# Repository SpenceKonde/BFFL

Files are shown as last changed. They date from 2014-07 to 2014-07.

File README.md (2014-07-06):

BFFL
====

Code and hardware specs for Big F'n FlashLight (BFFL)

Concept
====

The BFFL represents the extension of commercially available high power LED flashlights to their illogical conclusion. The BFFL uses a 150W LED emitter, and is powered by 24 18650 lithium ion batteries. The BFFL easily outshines typical home outdoor spotlights. 

Control
====
Control is provided by an ATtiny84 microcontroller. Control inputs consist of a trigger, brightness control, and standby light.  Brightness is adjustable down to 1/32 power via PWM, and it can set to run at 1/32 to 1/8 power when the trigger is not depressed (so you can find your way with it pointed down, and then press the trigger to get a much brighter search light) Battery status is displayed via an RGB led, and the temperature of the emitter is monitored to prevent overheating in the event of a cooling failure. The fan used has PWM control, and the speed of the fan is controlled by the measured temperature.

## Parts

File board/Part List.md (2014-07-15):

| ID | Part  | Notes |
| --- |---| -----|
| C1,C3,C4 | 0.1uf ceramic 1206 ||
| C2 | 22uf tantalum
| LED1 | DC-LED11119 5050 RGB LED | Battery status light |
| LED2 | Red 1206 LED | Temp. warning light|
| LED3 | Green 1206 LED |Power light|
| R1 | 1.2k Ohm 1206 | Ballast for LED2 |
| R2 | 470 Ohm 1206 | Ballast for LED3 |
| R3+ | 1.2k Ohm 1206 | Ballast for LED1, Green |
| R4+ | 470 Ohm 1206 | Ballast for LED1, Red |
| R5+ | 1.2k Ohm 1206 | Ballast for LED1, Blue |
| R6 | 10K Ohm | Vbat divider |
| R7 | 1k Ohm | Vbat divider |
| R8* | 1K Ohm | Pulldown for temp sensor |
| R9 | 10k Ohm | Pulldown for MOSFET |
|JP1| 2 pin KK-100 header | 12v in |
|JP2| 7 pin KK-100 header | controls |
|JP3| JP4: Screw terminals | LED |
|JP4| 3 pin KK-100 header | Temp |
|JP5| 4 pin KK-100 header** | Fan |
|JP6| 2x3 pin 0.1" header | AVR ISP |
| Q1 | AO4438 ||
| U1  | ATINY84A-SU-ND ||
| U2  | TLV1117-50CDCYR | 5v LDO regulator

** Tab on header must be shaved down in order to fit the PWM fan connector, which expects the keying tab to be the size that it is on a standard 3 pin KK-100 connector.

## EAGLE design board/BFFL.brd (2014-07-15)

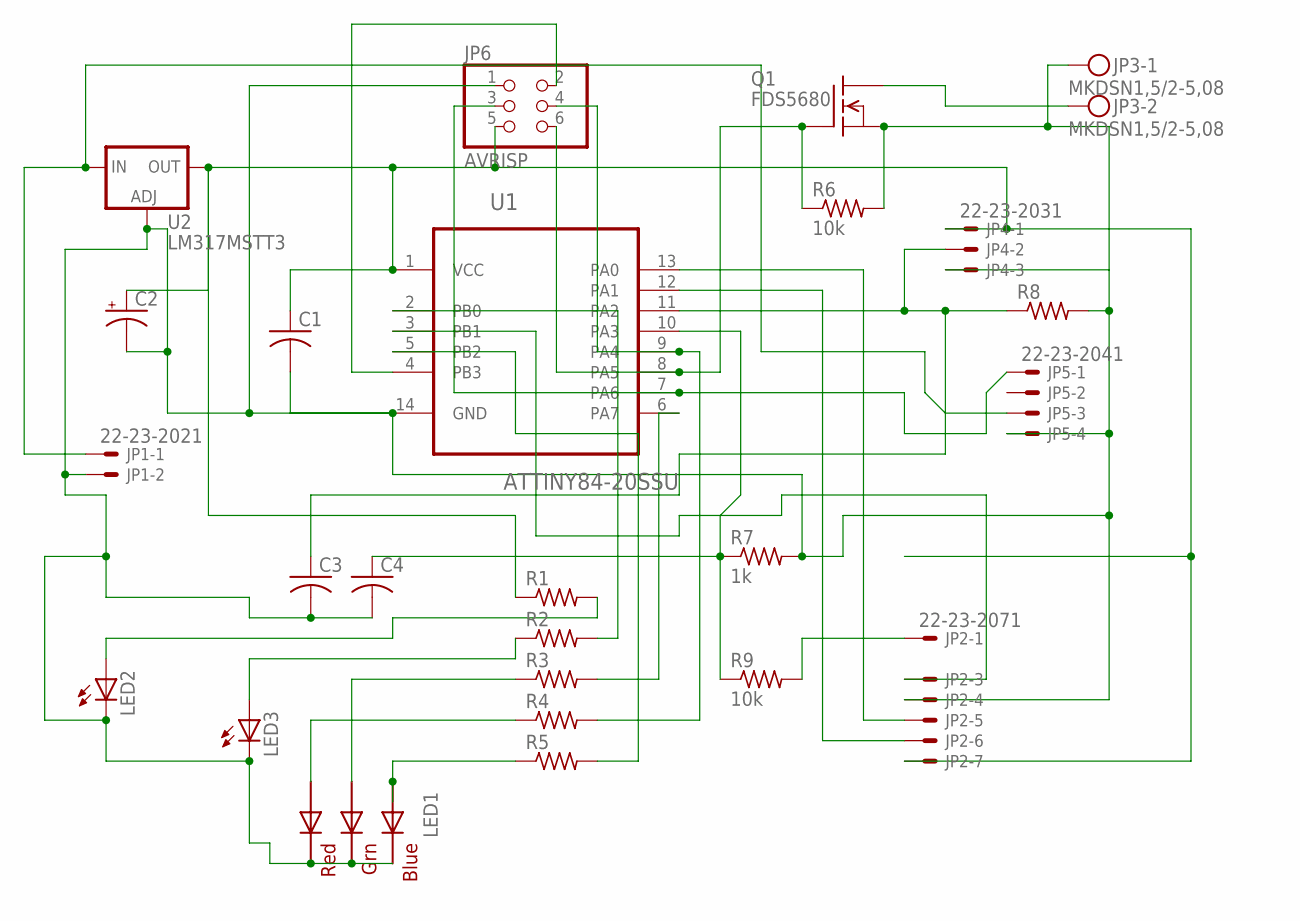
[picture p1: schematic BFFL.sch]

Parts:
C1, C3, C4: C-USC1206K; C1206K
C2: CPOL-USC/6032-28W; C/6032-28W
JP1: 22-23-2021
JP2: 22-23-2071
JP3: MKDSN1,5/2-5,08
JP4: 22-23-2031
JP5: 22-23-2041
JP6: AVRISP; 2X03
LED1: RGBLED5050
LED2, LED3: LEDCHIPLED_1206; CHIPLED_1206
Q1: FDS5680; SO-8
R1, R2, R3, R4, R5, R8: R-US_R1206; R1206
R6, R9: 10k; R1206
R7: 1k; R1206
U1: ATTINY84-20SSU; SOIC127P600X175-14N
U2: LM317MSTT3; SOT223

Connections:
unnamed: JP2.1, R9.2
unnamed: C4.1, R7.1, R9.1, U1.10 (PA3)
unnamed: JP1.1, JP5.3, U2.3 (IN)
unnamed: JP6.6, Q1.4 (G), R6.1, U1.8 (PA5)
unnamed: R2.2, U1.2 (PB0)
unnamed: C1.1, C2.+, JP2.7, JP4.1, JP6.5, R1.1, U1.1 (VCC), U2.4 (OUT)
unnamed: LED2.A, R1.2
unnamed: LED3.A, R2.1
unnamed: LED1.2 (RED_A), R4.1
unnamed: LED1.1 (GREEN_A), R3.1
unnamed: LED1.3 (BLUE_A), R5.1
unnamed: JP3.2, Q1.5 (D), Q1.6 (D), Q1.7 (D), Q1.8 (D)
unnamed: C1.2, C2.-, C3.2, C4.2, JP1.2, JP2.4, JP3.1, JP4.3, JP5.4, JP6.1, LED1.4 (BLUE_C), LED1.5 (RED_C), LED1.6 (GREEN_C), LED2.C, LED3.C, Q1.1 (S), Q1.2 (S), Q1.3 (S), R6.2, R7.2, R8.2, U1.14 (GND), U2.1 (ADJ)
unnamed: R5.2, U1.5 (PB2)
unnamed: R3.2, U1.6 (PA7)
unnamed: JP5.1, JP6.3, U1.7 (PA6)
unnamed: JP2.3, U1.3 (PB1)
unnamed: JP6.4, R4.2, U1.9 (PA4)
unnamed: C3.1, JP4.2, R8.1, U1.11 (PA2)
unnamed: JP2.5, U1.13 (PA0)
unnamed: JP2.6, U1.12 (PA1)
unnamed: JP6.2, U1.4 (PB3)

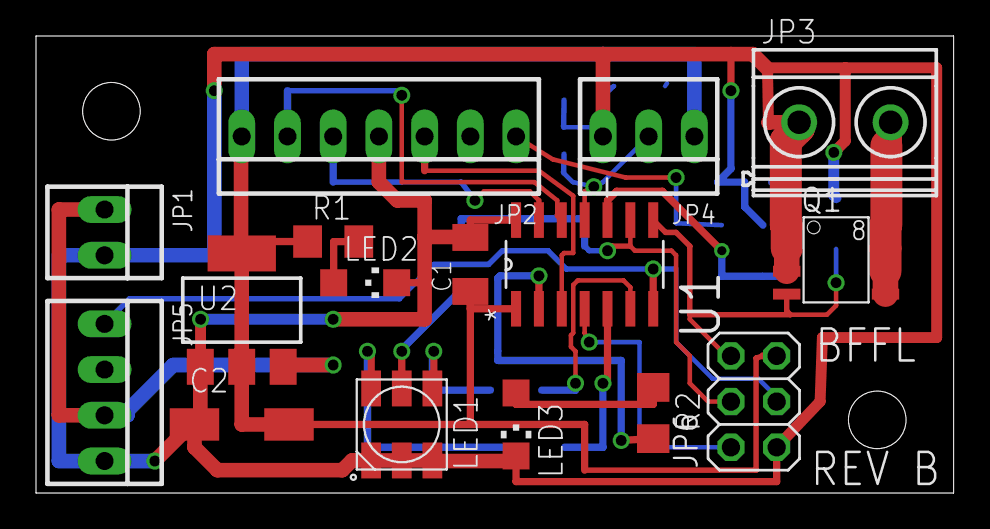
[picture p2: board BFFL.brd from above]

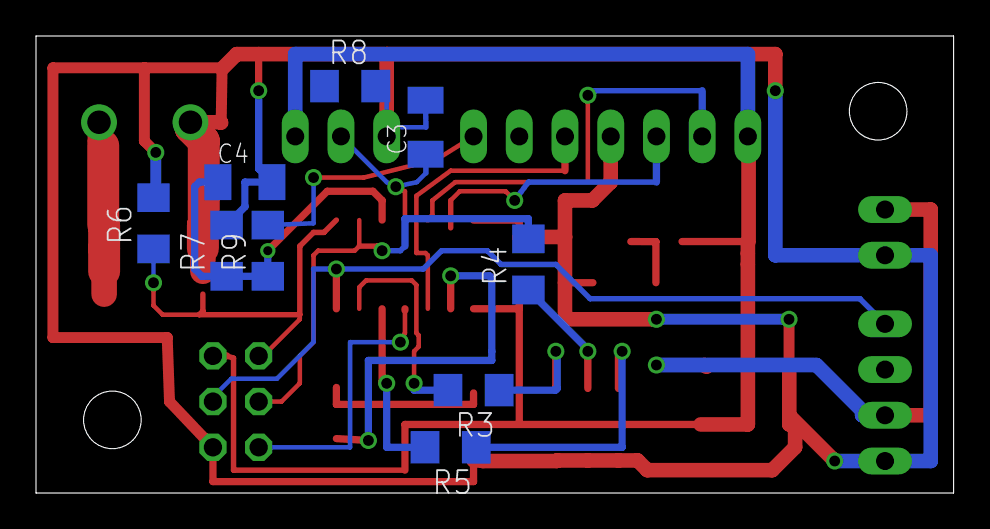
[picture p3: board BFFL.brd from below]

Board: 2 copper layers, 51.0 x 25.4 mm, 25 parts (9 on the bottom side), 22 nets.

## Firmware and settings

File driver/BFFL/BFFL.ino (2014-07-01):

#include <EEPROM.h>
int led_out=5;
int bat_lvl_low=4;
int bat_lvl_mid=7;
int bat_lvl_high=8;
int temp_led=10;
int idle_in=0;
int temp_in=2;
int v_in=3;
int fan_out=6;
int pwm_in=1;
int trig_in=9;
//int trig_in=0;
int cellcount=6;
//5v = 1024;
//3v minimum
//10:1 voltage division
int vlow=55*cellcount;
int vwarn=62*cellcount;
int vmid=68*cellcount;
int vhigh=76*cellcount;
// MCP9701A
// Vzero=400mv=82 from AnalogrRead()
// 19.7 (4 1024th's of 5v) per degree C
// Max temp 50C = 282
// warning temp = 45C 262
int twarn=262;
int tmax=282;
int tfan=202;
int idle_thresh=512;
int idle_min=8;
int idle_max=32;
int idle_div=400;
int min_bright=8;
int throttle_bright=160;
int tempblink=0;
int batblink=0;
int voltage_avg=0;
int lasttrig=1;
int temp_avg=0;
int batthrottle=0;
int batthrottlemargin=4;


void setup() {
  cellcount=EEPROM.read(0);
  vlow=EEPROM.read(4)*cellcount;
  vwarn=EEPROM.read(3)*cellcount;
  vhigh=EEPROM.read(1)*cellcount;
  vmid=EEPROM.read(2)*cellcount;
  batthrottlemargin=EEPROM.read(5);
  idle_thresh=EEPROM.read(0x0A)*4;
  idle_min=EEPROM.read(0x0B);
  idle_max=EEPROM.read(0x0C);
  idle_div=EEPROM.read(0x0D)*4;
  min_bright=EEPROM.read(0x0E);
  throttle_bright=EEPROM.read(0x0F);
  int tbase=EEPROM.read(0x10);
  twarn=tbase+EEPROM.read(0x12);
  tmax=tbase+EEPROM.read(0x11);
  tfan=tbase+EEPROM.read(0x13);
  pinMode(temp_in,INPUT);
  pinMode(pwm_in,INPUT);
  pinMode(trig_in,INPUT_PULLUP);
  pinMode(v_in,INPUT);
  pinMode(temp_led,OUTPUT);
  pinMode(led_out,OUTPUT);
  digitalWrite(led_out,0);
  pinMode(bat_lvl_low,OUTPUT);
  pinMode(bat_lvl_high,OUTPUT);
  pinMode(bat_lvl_mid,OUTPUT);
  pinMode(fan_out,OUTPUT);
  pinMode(idle_in,INPUT);
  voltage_avg=analogRead(v_in);
  temp_avg=analogRead(temp_in);
}


void loop() {
  int trig=digitalRead(trig_in);
  int voltage=analogRead(v_in);
  int temp=analogRead(temp_in);
  temp_avg=(temp_avg*9+temp)/10;
  voltage_avg=(voltage_avg*9+voltage)/10;
  int idle=analogRead(idle_in);
  //temp_avg=temp;
  //voltage_avg=voltage;
  if ((trig==1 && idle < idle_thresh) || temp_avg >= tmax || voltage_avg <= vlow) {
    digitalWrite(led_out,0);
  } else {
    if (temp_avg < tmax && ((voltage_avg > vlow) && ( lasttrig==0 || trig==1)) || (voltage_avg > vwarn)) { //don't let them turn it on if it's below vwarn but above vlow, but let them keep it on until it reaches vlow.
      int pwm_adjust=analogRead(pwm_in);
      pwm_adjust=max(min(pwm_adjust/3,255),min_bright);
      if (trig==1) { //idle mode 
        int tidle=idle-idle_thresh;
        tidle=(tidle*(idle_max-idle_min))/idle_div;
        tidle+=idle_min;
        tidle=min(tidle,idle_max);
        pwm_adjust=tidle;
      }
      if (temp_avg > twarn ||  voltage_avg < vwarn || (voltage_avg < (vwarn+batthrottlemargin*cellcount) && batthrottle==1)) {
        pwm_adjust=min(pwm_adjust,throttle_bright);
        
         if (voltage_avg < vwarn) {
           batthrottle=1;
         }
      } else   if (voltage_avg > (vwarn+batthrottlemargin*cellcount)) {
         batthrottle=0;
      }
      if (pwm_adjust==255) {
        digitalWrite(led_out,1);
      } else {
        analogWrite(led_out,pwm_adjust);
      }
    }
  }
  if (temp_avg > twarn) {
    digitalWrite(temp_led,1);
  } else {
    digitalWrite(temp_led,0);
  }
  if (voltage_avg > vhigh) {
    digitalWrite(bat_lvl_high,1);
    digitalWrite(bat_lvl_mid,0);
    digitalWrite(bat_lvl_low,0);
  }else if (voltage_avg > vmid) {
    int brt=(255*(voltage_avg-vmid))/(vhigh-vmid);
    analogWrite(bat_lvl_high,brt);
    analogWrite(bat_lvl_mid,255-brt);
    digitalWrite(bat_lvl_low,0);
  } else if (voltage_avg > vwarn) {
    digitalWrite(bat_lvl_mid,1);
    digitalWrite(bat_lvl_low,0);
    digitalWrite(bat_lvl_high,0);
  } else if (voltage_avg > vlow) {
    int brt=(255*(voltage_avg-vlow))/(vwarn-vlow);
    digitalWrite(bat_lvl_low,1);
    analogWrite(bat_lvl_mid,brt);
    digitalWrite(bat_lvl_high,0);
  } else {
    digitalWrite(bat_lvl_low,1);
    digitalWrite(bat_lvl_mid,0);
    digitalWrite(bat_lvl_high,0);
  }
  if (temp_avg > twarn) {
    digitalWrite(fan_out,1); //turn fan on full blast!
  } else if (temp_avg > tfan) {
    analogWrite(fan_out,134+(temp_avg-tfan)*2);
  } else {
    digitalWrite(fan_out,0);
  }
}





/*
void loop() {
  int trig=digitalRead(trig_in);
  int voltage=analogRead(v_in);
  int temp=analogRead(temp_in);
  temp_avg=(temp_avg*9+temp)/10;
  voltage_avg=(voltage_avg*9+voltage)/10;
  int idle=analogRead(idle_in);
  //int idle=0;
  //temp_avg=temp;
  //voltage_avg=voltage;
  if ( (trig==1 || idle > idle_thresh) || temp_avg >= tmax || voltage_avg <= vlow) {
    digitalWrite(led_out,0);
  } else {
    if (temp_avg < tmax && ((voltage_avg > vlow) && lasttrig==0) || (voltage_avg > vwarn)) { //don't let them turn it on if it's below vwarn but above vlow, but let them keep it on until it reaches vlow.
      int pwm_adjust=analogRead(pwm_in);
      if (trig==1) { //idle mode 
        int tidle=idle-idle_thresh;
        tidle=(tidle*(idle_max-idle_min))/idle_div;
        tidle+=idle_min;
        tidle=min(tidle,idle_max);
        pwm_adjust=tidle;
      }
      pwm_adjust=max(min(pwm_adjust/3,255),min_bright);
      if (temp_avg > twarn ||  voltage_avg < vwarn || (voltage_avg < (vwarn+batthrottlemargin*cellcount) && batthrottle==1)) {
        pwm_adjust=min(pwm_adjust,throttle_bright);
         if (voltage_avg < vwarn) {
           batthrottle=1;
         }
      } else   if (voltage_avg > (vwarn+batthrottlemargin*cellcount)) {
         batthrottle=0;
      }
      if (pwm_adjust==255) {
        digitalWrite(led_out,1);
      } else {
        analogWrite(led_out,pwm_adjust);
      }
    }
  }
  if (temp_avg > twarn) {
    digitalWrite(temp_led,1);
  } else {
    digitalWrite(temp_led,0);
  }
  if (voltage_avg > vhigh) {
    digitalWrite(bat_lvl_high,1);
    digitalWrite(bat_lvl_mid,0);
    digitalWrite(bat_lvl_low,0);
  }else if (voltage_avg > vmid) {
    int brt=(255*(voltage_avg-vmid))/(vhigh-vmid);
    analogWrite(bat_lvl_high,brt);
    analogWrite(bat_lvl_mid,255-brt);
    digitalWrite(bat_lvl_low,0);
  } else if (voltage_avg > vwarn) {
    digitalWrite(bat_lvl_mid,1);
    digitalWrite(bat_lvl_low,0);
    digitalWrite(bat_lvl_high,0);
  } else if (voltage_avg > vlow) {
    int brt=(255*(voltage_avg-vlow))/(vwarn-vlow);
    digitalWrite(bat_lvl_low,1);
    analogWrite(bat_lvl_mid,brt);
    digitalWrite(bat_lvl_high,0);
  } else {
    digitalWrite(bat_lvl_low,1);
    digitalWrite(bat_lvl_mid,0);
    digitalWrite(bat_lvl_high,0);
  }
  if (temp_avg > twarn) {
    digitalWrite(fan_out,1); //turn fan on full blast!
  } else if (temp_avg > tfan) {
    analogWrite(fan_out,134+(temp_avg-tfan)*2);
  } else {
    digitalWrite(fan_out,0);
  }
}
*/

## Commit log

2014-07-01 Organize, add eagle files
    [BFFL.brd, BFFL.sch]
2014-07-13 Rev B of PCB, preliminary
    Corrects multiple faults in Rev A and improves mounting options.
    Silkscreen still needs to be done.
    [BFFL.brd, BFFL.sch]
2014-07-15 Update board
    [BFFL.brd, BFFL.sch]
2014-07-15 Move sketch into folder
    This allows the arduino IDE to open it without having to move the file
    around manually.
